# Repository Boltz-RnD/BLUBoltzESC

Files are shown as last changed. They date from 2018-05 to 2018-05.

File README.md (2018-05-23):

# DarkESC

A Remixed Board Design from The BlueESC with a large footprint and Utilizing easy to source components for a DIYer.

I've made this ESC Board Design for a College Project,but you can use it wherever however you want.

Although it may look a DIY Design but is no diffrent than a 60A version of BlueESC, It runs on a Forked Version of Simonk's TGY firmware.

Unlike other DIY ESC, This one is a lot more reliable and is much more Optimized (Thanks to the TGY Firmware). 

The Firmware for this ESC is same as that of BlueESC and can be found at https://github.com/bluerobotics/tgy

Feel Free to Contribute and develop A better smaller but still DIY-able ESC.

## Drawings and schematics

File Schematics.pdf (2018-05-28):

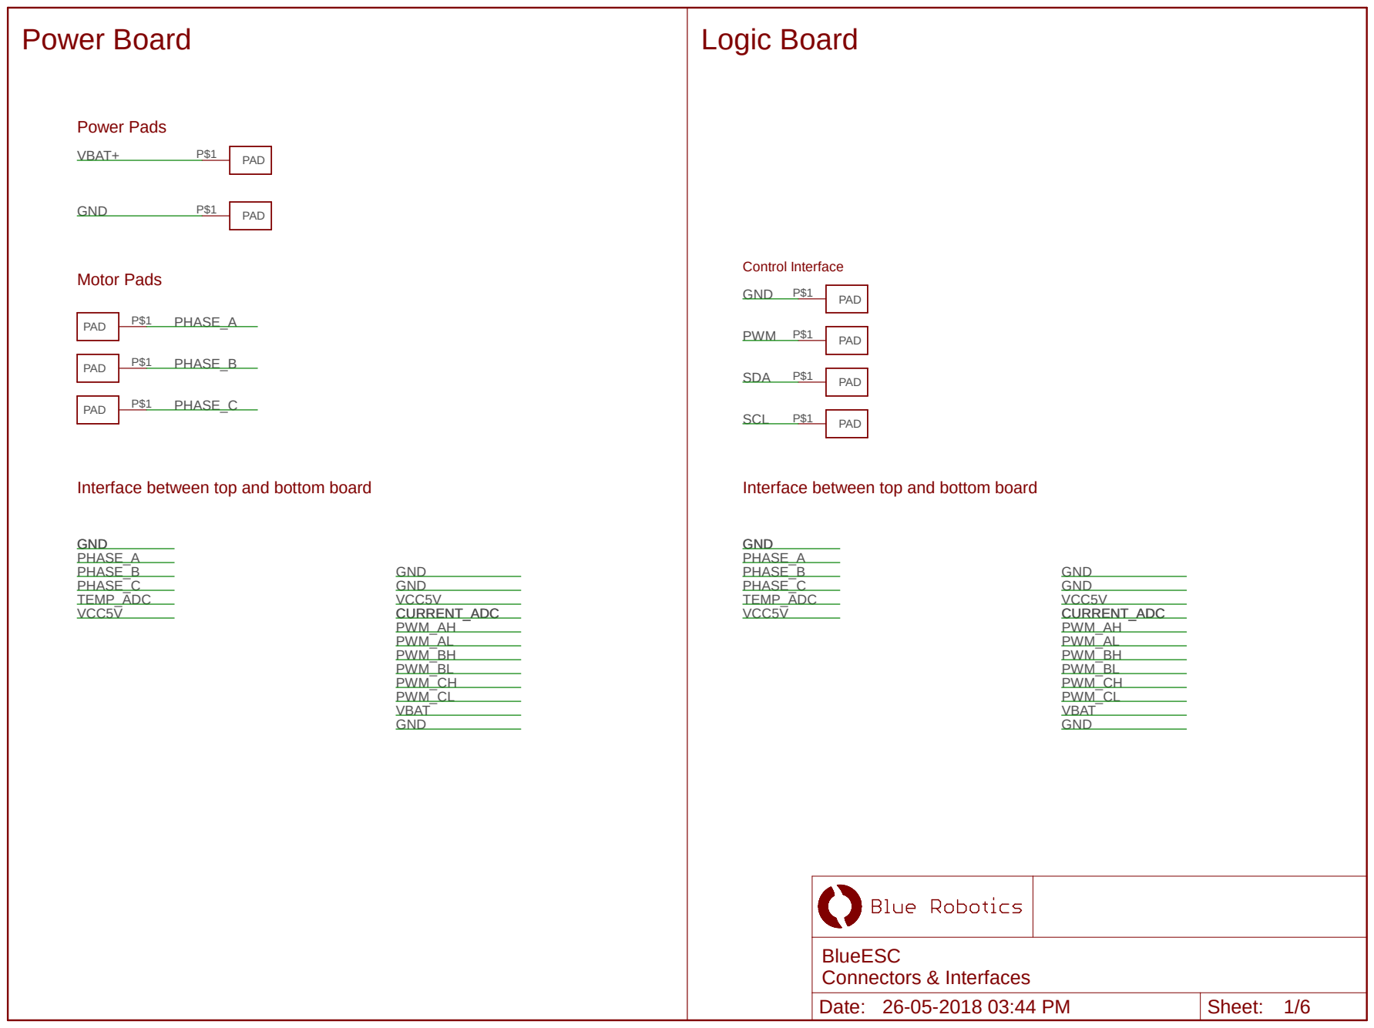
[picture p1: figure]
PAD; PAD P$1; GND; PHASE_A; PHASE_B; PHASE_C; VBAT; PWM_AL; PWM_BL; PWM_CL; TEMP_ADC; PWM_CH; PWM_BH; PWM_AH; CURRENT_ADC CURRENT_ADC; VBAT+; VCC5V; SDA; SCL; PWM; Power Pads; Motor Pads; Interface between top and bottom board; Control Interface; Power Board; Logic Board; Date: 26-05-2018 03:44 PM; Sheet: 1/6; BlueESC Connectors & Interfaces

# TP4 TP⁵ TP⁶

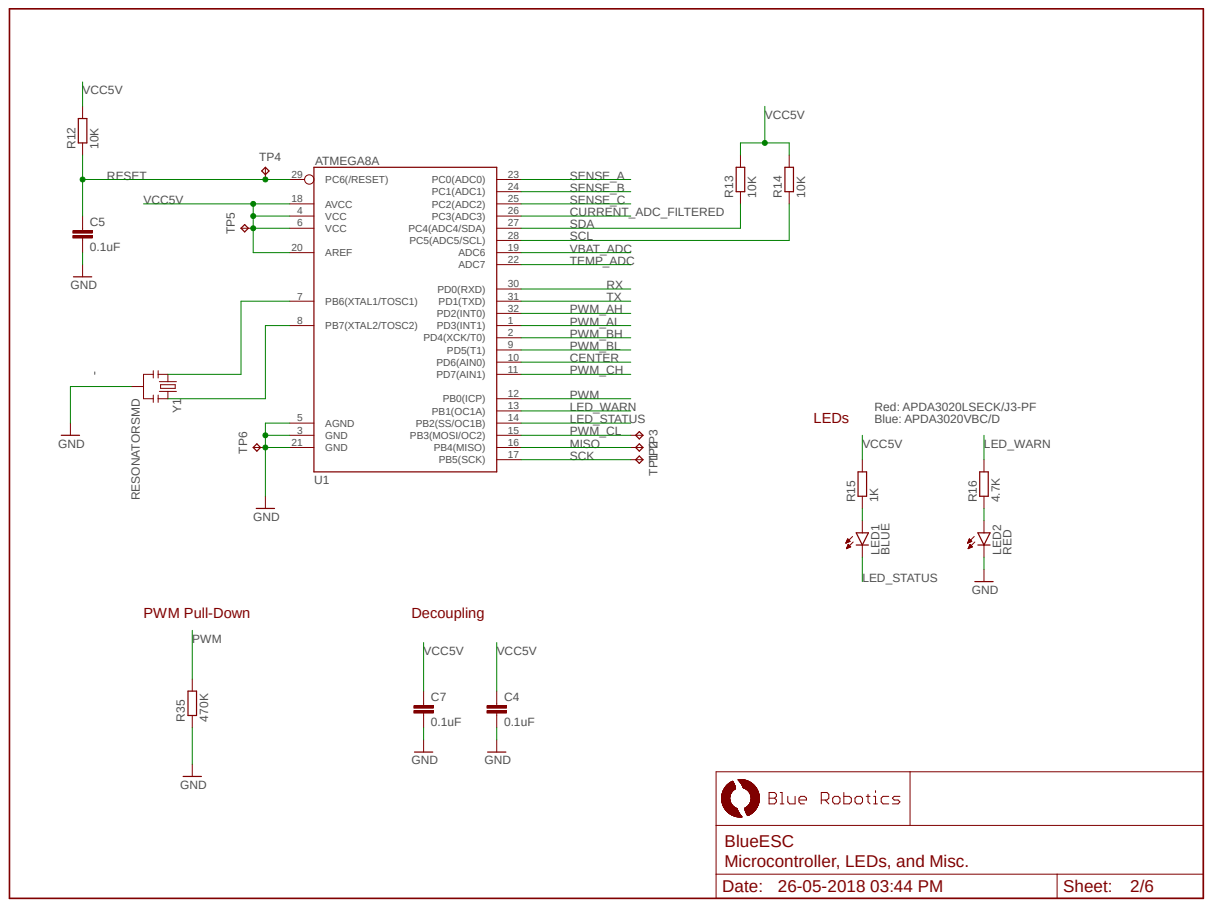
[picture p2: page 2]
ATMEGA8A; Red: APDA3020LSECK/J3-PF; Blue: APDA3020VBC/D ¹⁰K; GND; RESONATORSMD; BLUE; RED 470K; PB5(SCK); PB7(XTAL2/TOSC2) 8; PB6(XTAL1/TOSC1) 7; GND 3 GND 21; VCC 4 VCC 6; AGND 5; AREF 20; AVCC 18; PB4(MISO); 16 PB3(MOSI/OC2); 13 PB0(ICP); PD7(AIN1); 11 PD6(AIN0); PD4(XCK/T0); PD3(INT1); PD2(INT0); 32 PD1(TXD); 31 PD0(RXD); ADC7; 22 ADC6; 19 PC5(ADC5/SCL); 28 PC4(ADC4/SDA); 27 PC3(ADC3); 26 PC2(ADC2); 25 PC1(ADC1); 24 PC0(ADC0); 23 PC6(/RESET) 29; U1 R¹²; R¹³; R¹⁴ Y¹; R¹⁵; R¹⁶; LED¹; LED² R³⁵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

PWM Pull-Down

BlueESC
Microcontroller, LEDs, and Misc.

# R34R¹⁰ R¹¹

Power Board | Logic Board

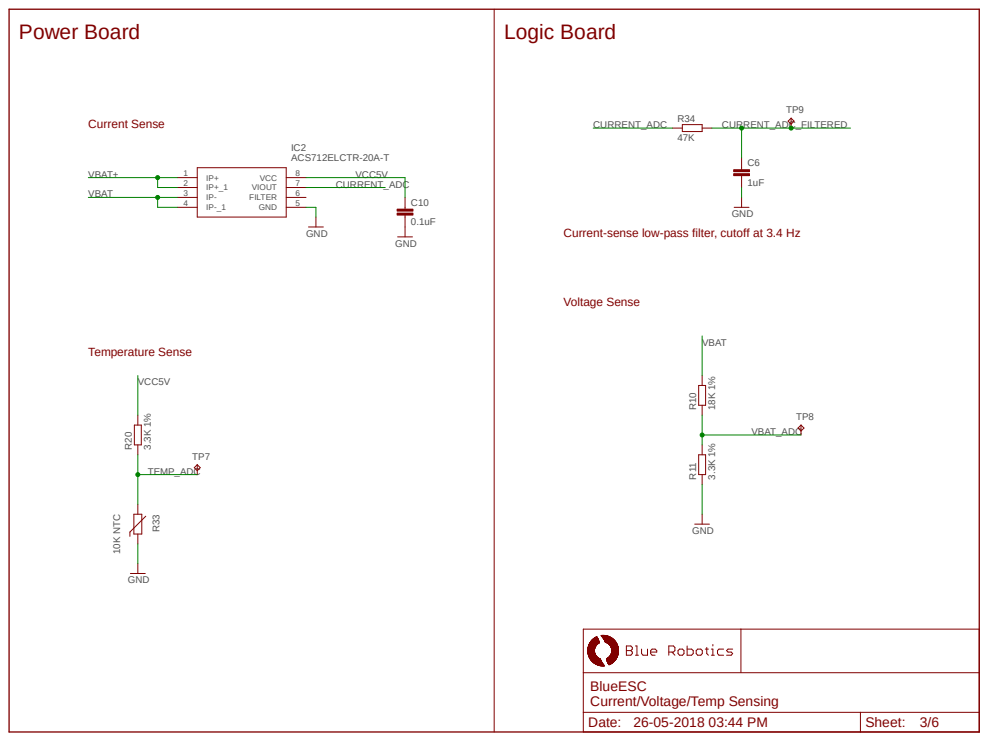
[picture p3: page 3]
GND 18K ¹% 3.3K ¹%; GND; GND 3.3K ¹% 10K NTC; ACS712ELCTR-20A-T; C10 R²⁰; R³³; VCC; VIOUT; FILTER; TP9 CURRENT_ADC_FILTERED; VBAT_ADC; VBAT; CURRENT_ADC; VBAT+; TEMP_ADC; VCC5V; Voltage Sense; Current Sense; Temperature Sense; Date: 26-05-2018 03:44 PM; Sheet: 3/6

Current-sense low-pass filter, cutoff at 3.4 Hz

BlueESC
Current/Voltage/Temp Sensing

Power Board | Logic Board

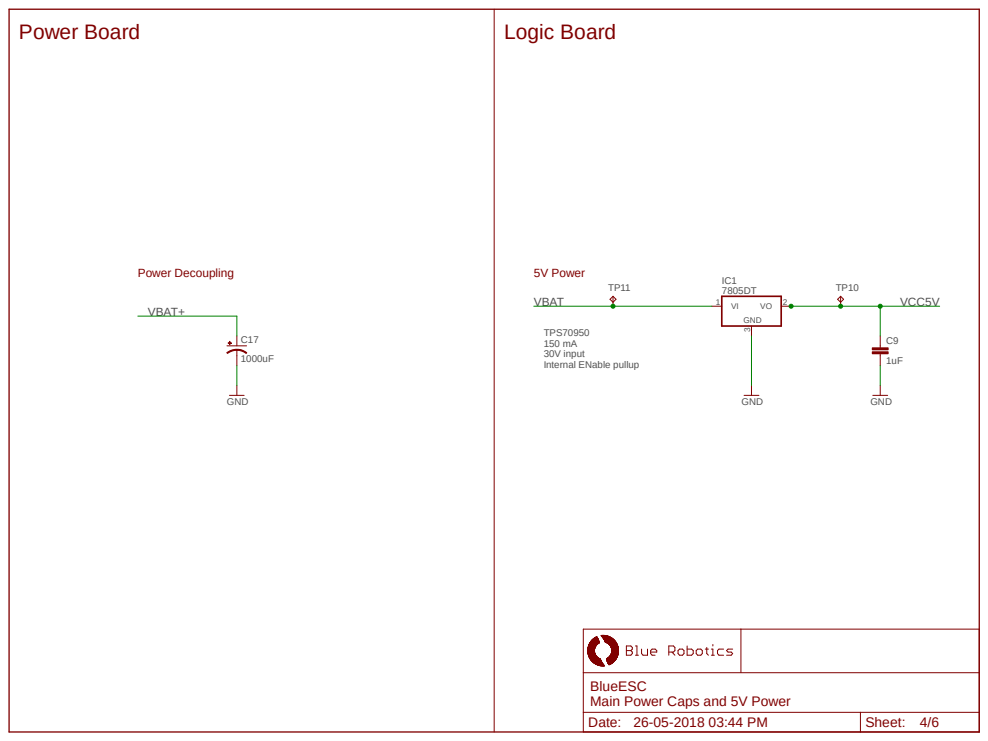
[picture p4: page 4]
TPS70950 150 mA 30V input; GND; VBAT+; VBAT; VCC5V; Power Decoupling; 5V Power; Date: 26-05-2018 03:44 PM; Sheet: 4/6

Internal ENable pullup 1000uF

BlueESC
Main Power Caps and 5V Power

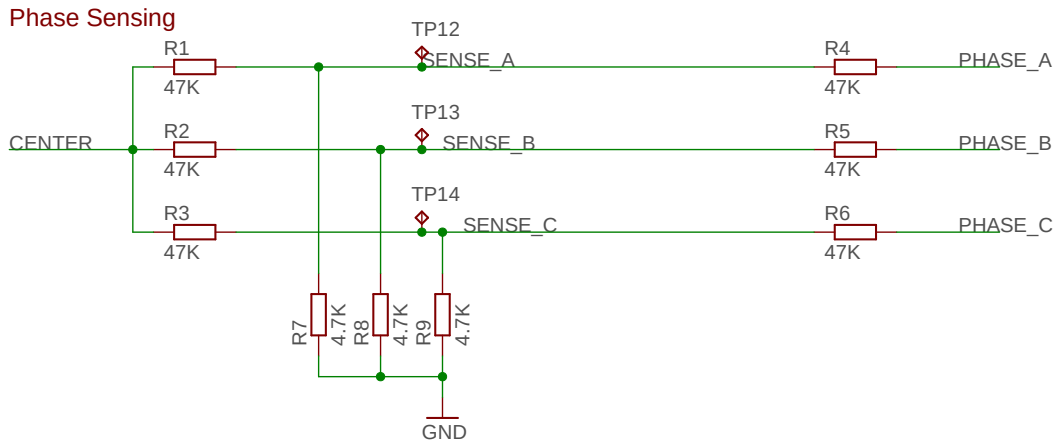
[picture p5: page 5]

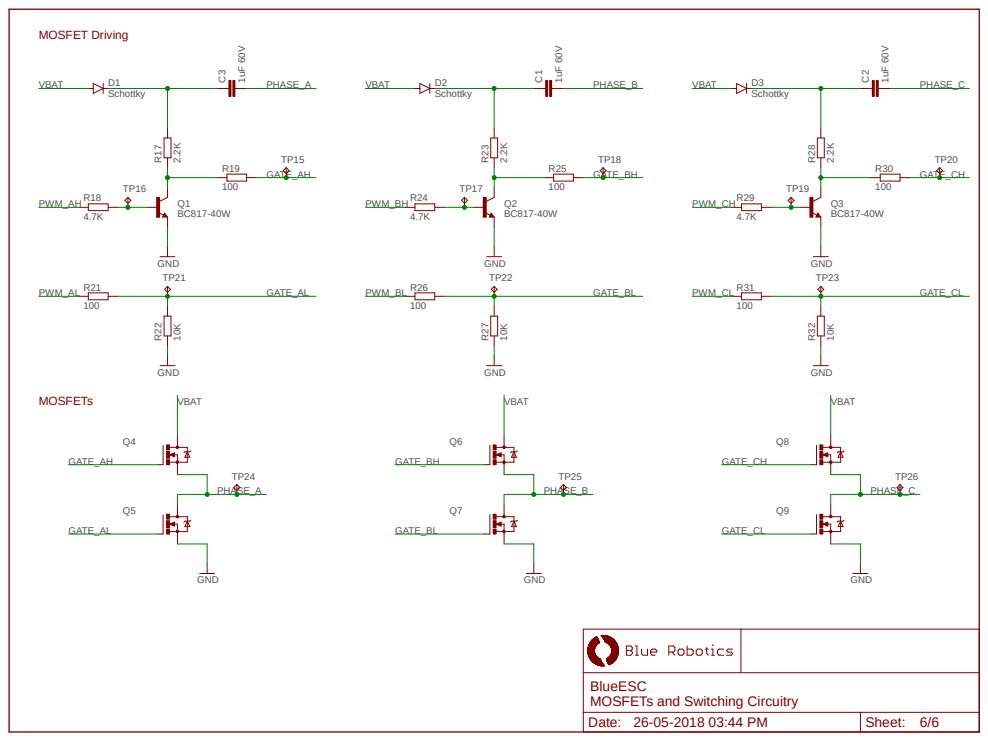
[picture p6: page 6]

BlueESC
MOSFETs and Switching Circuitry

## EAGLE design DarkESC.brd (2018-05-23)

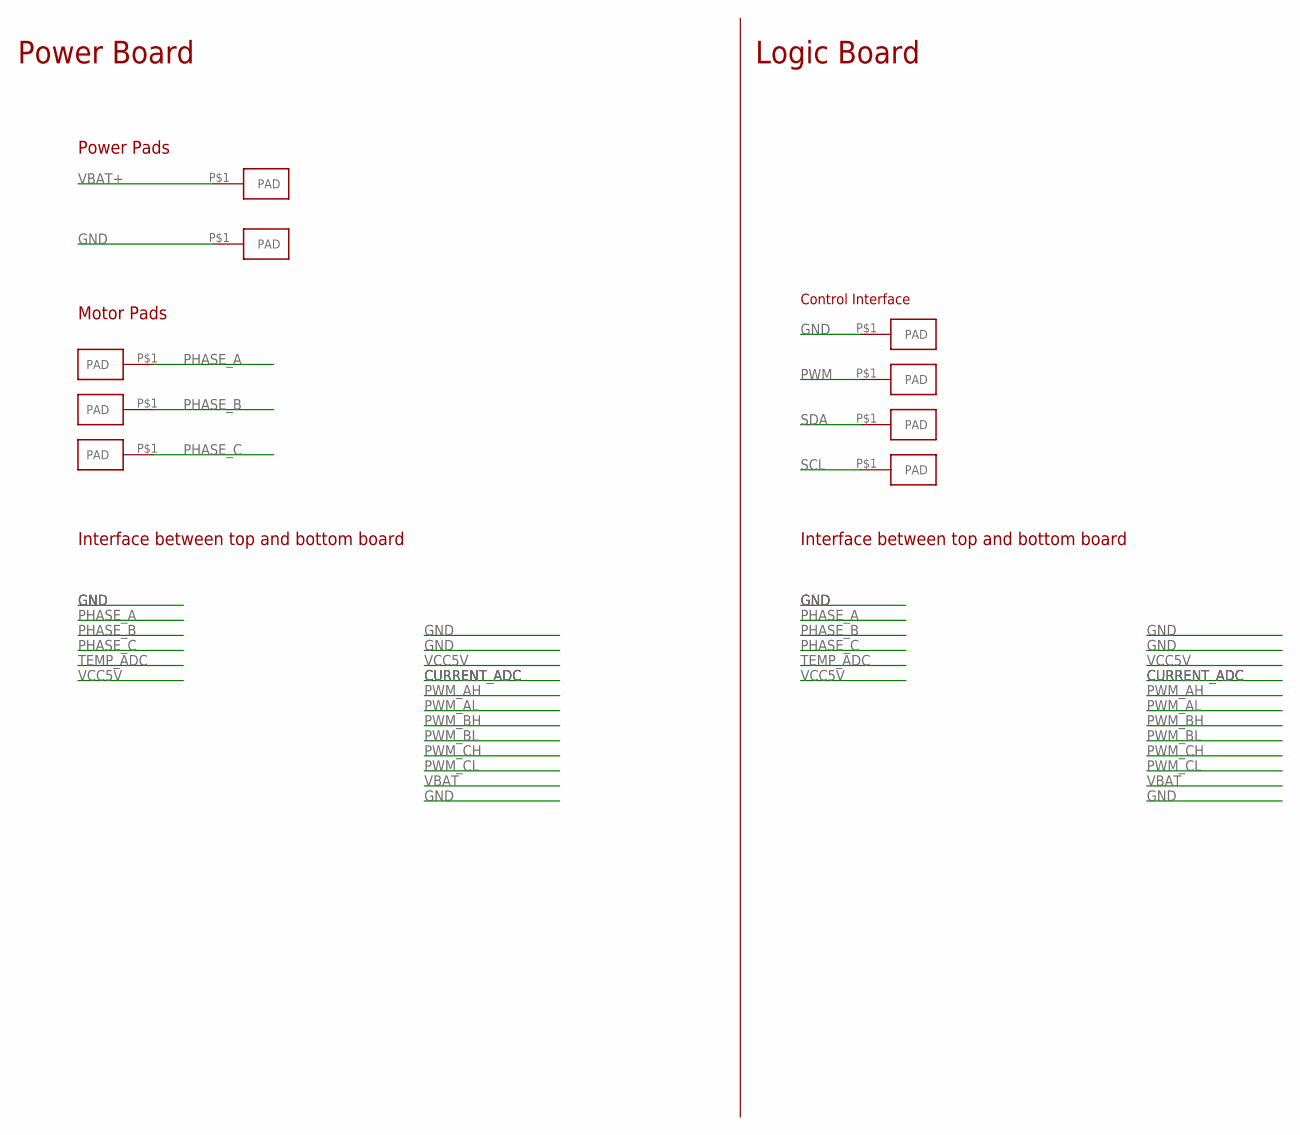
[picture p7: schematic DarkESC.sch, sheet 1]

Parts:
U$1, U$2: PADPTH-MED; PAD-PTH-MED-1
U$5, U$6, U$7: PAD18AWG; PAD-PTH-18AWG-1
U$11, U$12, U$13, U$14: PAD1.5X3MM; PAD-1.5X3MM

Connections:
GND: U$2.P$1, U$11.P$1; also elsewhere on the board
PHASE_A: U$5.P$1; also elsewhere on the board
PHASE_B: U$6.P$1; also elsewhere on the board
PHASE_C: U$7.P$1; also elsewhere on the board
PWM: U$14.P$1; also elsewhere on the board
SCL: U$13.P$1; also elsewhere on the board
SDA: U$12.P$1; also elsewhere on the board
VBAT+: U$1.P$1; also elsewhere on the board

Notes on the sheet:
Power Pads
Motor Pads
Interface between top and bottom board
Control Interface
Power Board
Logic Board

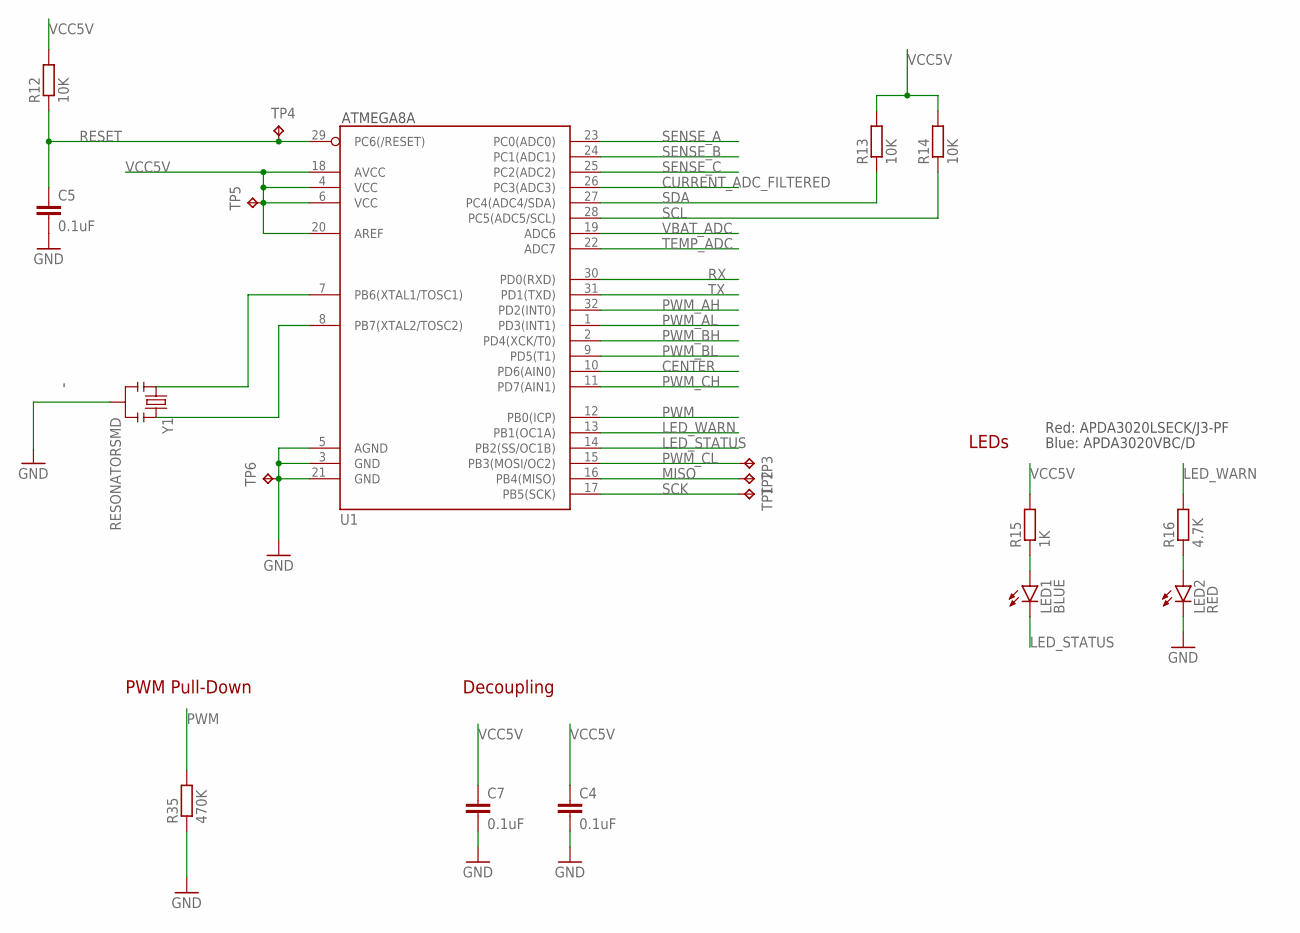
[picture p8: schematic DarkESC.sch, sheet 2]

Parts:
C4, C5, C7: 0.1uF; C3216
LED1: BLUE; SMT-LED-3X2-RA
LED2: RED; SMT-LED-3X2-RA
R12, R13, R14: 10K; R3216
R15: 1K; R3216
R16: 4.7K; R3216
R35: 470K; R3216
TP1, TP2, TP3, TP4, TP5, TP6: TPB1,27; B1,27
U1: ATMEGA168; TQFP32-08
Y1: RESONATORSMD; RESONATOR-SMD

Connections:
CENTER: U1.10 (PD6(AIN0)); also elsewhere on the board
CURRENT_ADC_FILTERED: U1.26 (PC3(ADC3)); also elsewhere on the board
GND: C4.2, C5.2, C7.2, LED2.2 (C), R35.1, TP6.TP, U1.3 (GND), U1.5 (AGND), U1.21 (GND), Y1.2; also elsewhere on the board
LED_STATUS: LED1.2 (C), U1.14 (PB2(SS/OC1B))
LED_WARN: R16.2, U1.13 (PB1(OC1A))
MISO: TP2.TP, U1.16 (PB4(MISO))
unnamed: LED2.1 (A), R16.1
unnamed: U1.7 (PB6(XTAL1/TOSC1)), Y1.1
unnamed: U1.8 (PB7(XTAL2/TOSC2)), Y1.3
unnamed: LED1.1 (A), R15.1
PWM: R35.2, U1.12 (PB0(ICP)); also elsewhere on the board
PWM_AH: U1.32 (PD2(INT0)); also elsewhere on the board
PWM_AL: U1.1 (PD3(INT1)); also elsewhere on the board
PWM_BH: U1.2 (PD4(XCK/T0)); also elsewhere on the board
PWM_BL: U1.9 (PD5(T1)); also elsewhere on the board
PWM_CH: U1.11 (PD7(AIN1)); also elsewhere on the board
PWM_CL: TP3.TP, U1.15 (PB3(MOSI/OC2)); also elsewhere on the board
RESET: C5.1, R12.1, TP4.TP, U1.29 (PC6(/RESET))
RX: U1.30 (PD0(RXD))
SCK: TP1.TP, U1.17 (PB5(SCK))
SCL: R14.1, U1.28 (PC5(ADC5/SCL)); also elsewhere on the board
SDA: R13.1, U1.27 (PC4(ADC4/SDA)); also elsewhere on the board
SENSE_A: U1.23 (PC0(ADC0)); also elsewhere on the board
SENSE_B: U1.24 (PC1(ADC1)); also elsewhere on the board
SENSE_C: U1.25 (PC2(ADC2)); also elsewhere on the board
TEMP_ADC: U1.22 (ADC7); also elsewhere on the board
TX: U1.31 (PD1(TXD))
VBAT_ADC: U1.19 (ADC6); also elsewhere on the board
VCC5V: C4.1, C7.1, R12.2, R13.2, R14.2, R15.2, TP5.TP, U1.4 (VCC), U1.6 (VCC), U1.18 (AVCC), U1.20 (AREF); also elsewhere on the board

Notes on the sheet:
ATMEGA8A
Decoupling
LEDs
Red: APDA3020LSECK/J3-PF
Blue: APDA3020VBC/D
PWM Pull-Down

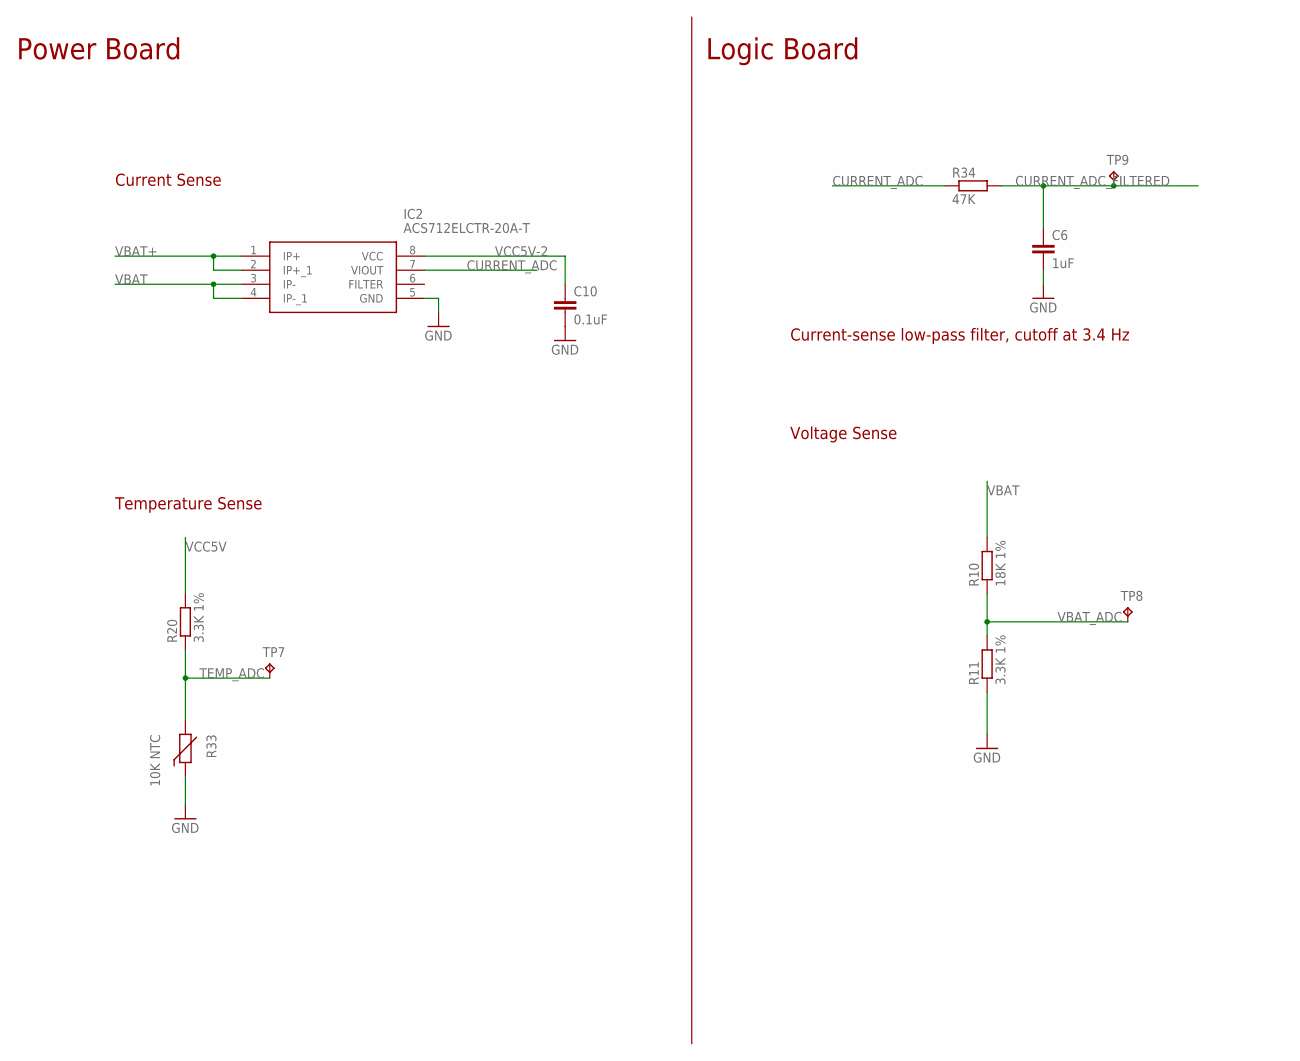
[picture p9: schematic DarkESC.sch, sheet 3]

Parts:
C6: 1uF; C3216
C10: 0.1uF; C3216
IC2: ACS712ELCTR-20A-T; SOIC127P600X175-8N
R10: 18K 1%; 0204/7
R11, R20: 3.3K 1%; 0204/7
R33: 10K NTC; RS-2,5
R34: 47K; R3216
TP7, TP8, TP9: TPB1,27; B1,27

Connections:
CURRENT_ADC: IC2.7 (VIOUT), R34.1
CURRENT_ADC_FILTERED: C6.1, R34.2, TP9.TP; also elsewhere on the board
GND: C6.2, C10.2, IC2.5 (GND), R11.1, R33.1; also elsewhere on the board
TEMP_ADC: R20.1, R33.2, TP7.TP; also elsewhere on the board
VBAT: IC2.3 (IP-), IC2.4 (IP-_1), R10.2; also elsewhere on the board
VBAT+: IC2.1 (IP+), IC2.2 (IP+_1); also elsewhere on the board
VBAT_ADC: R10.1, R11.2, TP8.TP; also elsewhere on the board
VCC5V: R20.2; also elsewhere on the board
VCC5V-2: C10.1, IC2.8 (VCC)

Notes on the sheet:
Power Board
Logic Board
Current-sense low-pass filter, cutoff at 3.4 Hz
Voltage Sense
Current Sense
Temperature Sense

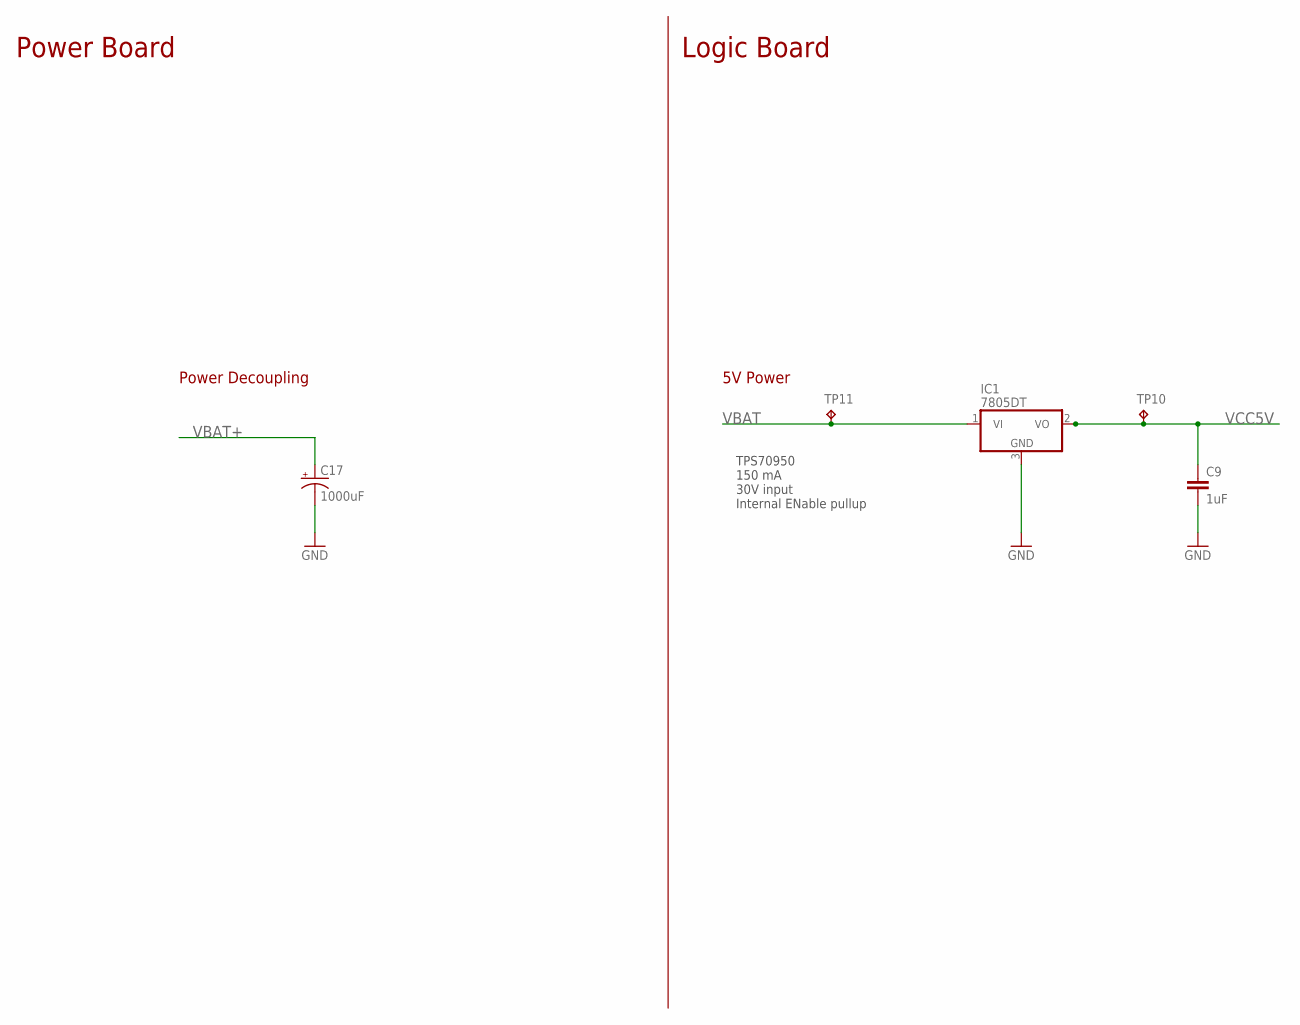
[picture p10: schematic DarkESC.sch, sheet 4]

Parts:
C9: 1uF; C3216
C17: 1000uF; CPOL-RADIAL-100UF-25V
IC1: 7805DT; TO252
TP10, TP11: TPB1,27; B1,27

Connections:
GND: C9.2, C17.2 (-), IC1.3 (GND); also elsewhere on the board
VBAT: IC1.1 (VI), TP11.TP; also elsewhere on the board
VBAT+: C17.1 (+); also elsewhere on the board
VCC5V: C9.1, IC1.2 (VO), TP10.TP; also elsewhere on the board

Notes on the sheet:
Power Board
Logic Board
Power Decoupling
5V Power
TPS70950 150 mA 30V input Internal ENable pullup

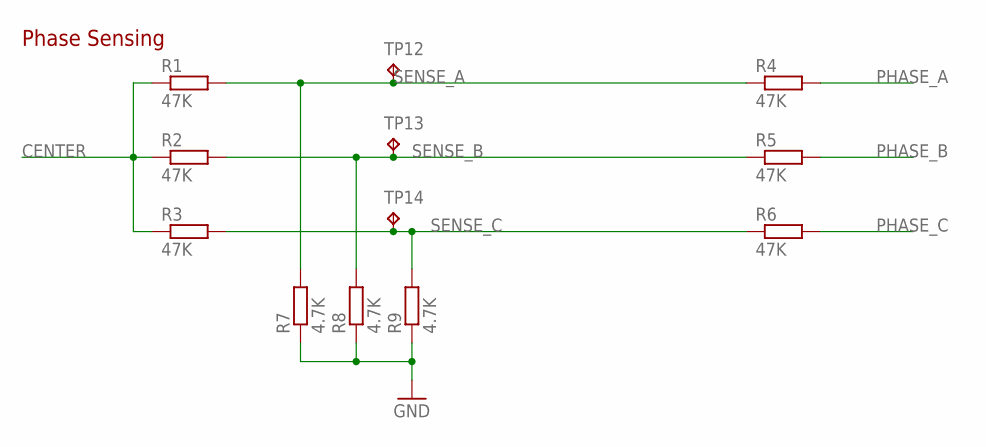
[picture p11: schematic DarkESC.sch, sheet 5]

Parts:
R1, R2, R3, R4, R5, R6: 47K; R3216
R7, R8, R9: 4.7K; R3216
TP12, TP13, TP14: TPB1,27; B1,27

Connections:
CENTER: R1.1, R2.1, R3.1; also elsewhere on the board
GND: R7.1, R8.1, R9.1; also elsewhere on the board
PHASE_A: R4.2; also elsewhere on the board
PHASE_B: R5.2; also elsewhere on the board
PHASE_C: R6.2; also elsewhere on the board
SENSE_A: R1.2, R4.1, R7.2, TP12.TP; also elsewhere on the board
SENSE_B: R2.2, R5.1, R8.2, TP13.TP; also elsewhere on the board
SENSE_C: R3.2, R6.1, R9.2, TP14.TP; also elsewhere on the board

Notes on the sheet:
Phase Sensing

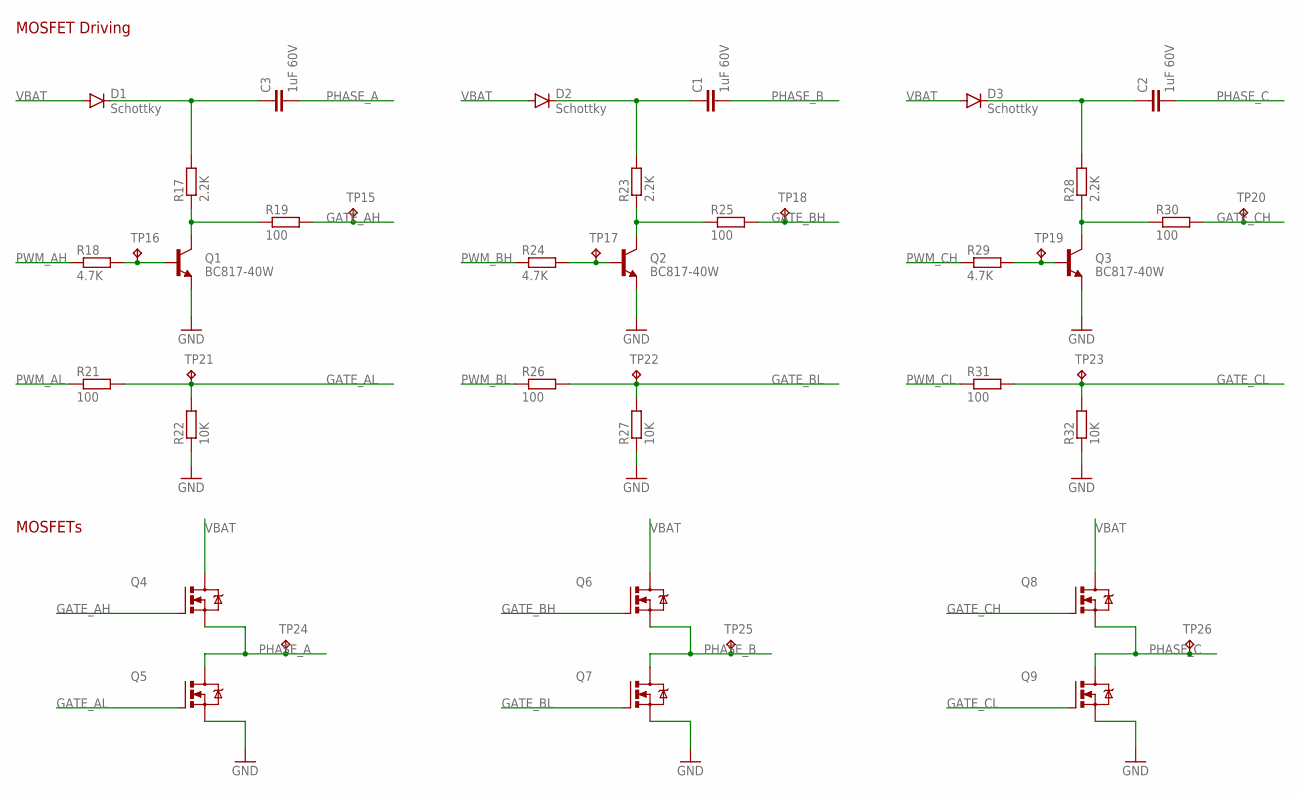
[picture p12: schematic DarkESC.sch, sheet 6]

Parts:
C1, C2, C3: 1uF 60V; C3216
D1, D2, D3: Schottky; SMB-DIODE
Q1, Q2, Q3: BC817-40W; SOT23
Q4, Q5, Q6, Q7, Q8, Q9: IRF520; TO220BV
R17, R23, R28: 2.2K; R3216
R18, R24, R29: 4.7K; R3216
R19, R21, R25, R26, R30, R31: 100; R3216
R22, R27, R32: 10K; R3216
TP15, TP16, TP17, TP18, TP19, TP20, TP21, TP22, TP23, TP24, TP25, TP26: TPB1,27; B1,27

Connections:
GATE_AH: Q4.G, R19.2, TP15.TP
GATE_AL: Q5.G, R21.2, R22.2, TP21.TP
GATE_BH: Q6.G, R25.2, TP18.TP
GATE_BL: Q7.G, R26.2, R27.2, TP22.TP
GATE_CH: Q8.G, R30.2, TP20.TP
GATE_CL: Q9.G, R31.2, R32.2, TP23.TP
GND: Q1.2 (E), Q2.2 (E), Q3.2 (E), Q5.S, Q7.S, Q9.S, R22.1, R27.1, R32.1; also elsewhere on the board
unnamed: Q1.1 (B), R18.2, TP16.TP
unnamed: Q1.3 (C), R17.1, R19.1
unnamed: Q2.1 (B), R24.2, TP17.TP
unnamed: Q2.3 (C), R23.1, R25.1
unnamed: Q3.1 (B), R29.2, TP19.TP
unnamed: Q3.3 (C), R28.1, R30.1
unnamed: C3.1, D1.C, R17.2
unnamed: C1.1, D2.C, R23.2
unnamed: C2.1, D3.C, R28.2
PHASE_A: C3.2, Q4.S, Q5.D, TP24.TP; also elsewhere on the board
PHASE_B: C1.2, Q6.S, Q7.D, TP25.TP; also elsewhere on the board
PHASE_C: C2.2, Q8.S, Q9.D, TP26.TP; also elsewhere on the board
PWM_AH: R18.1; also elsewhere on the board
PWM_AL: R21.1; also elsewhere on the board
PWM_BH: R24.1; also elsewhere on the board
PWM_BL: R26.1; also elsewhere on the board
PWM_CH: R29.1; also elsewhere on the board
PWM_CL: R31.1; also elsewhere on the board
VBAT: D1.A, D2.A, D3.A, Q4.D, Q6.D, Q8.D; also elsewhere on the board

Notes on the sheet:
MOSFETs
MOSFET Driving

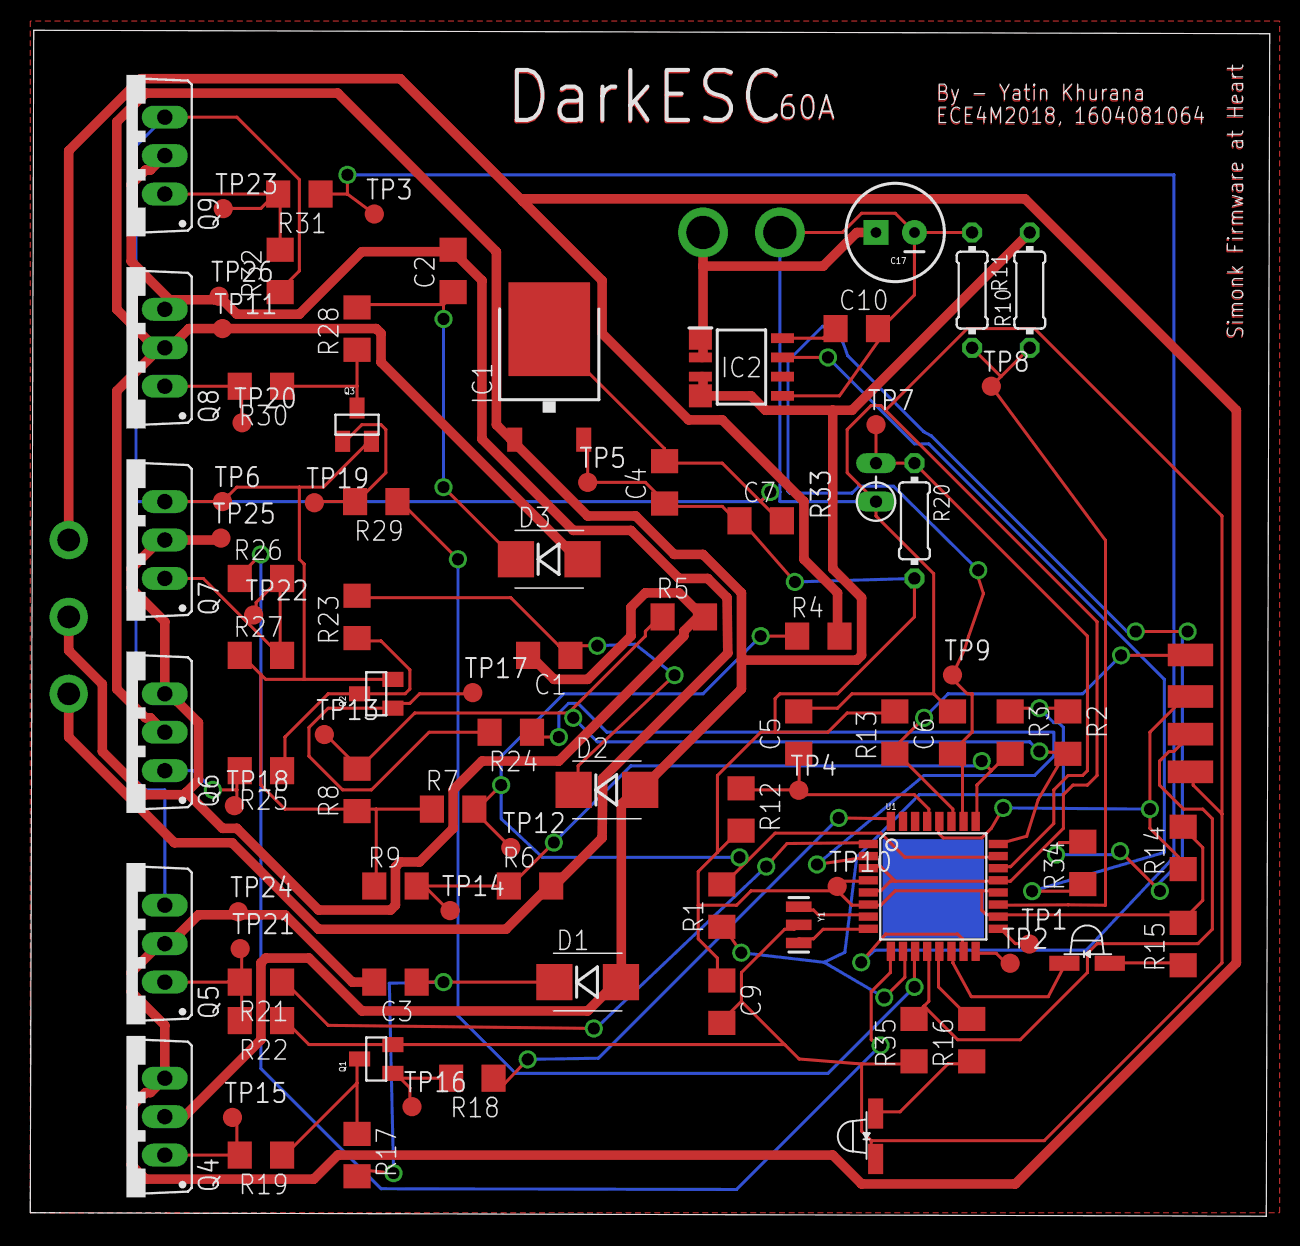
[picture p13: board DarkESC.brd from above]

Board: 2 copper layers, 81.9 x 78.4 mm, 98 parts (0 on the bottom side), 49 nets.

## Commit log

2018-03-31 Version 1.1 For BlueBoltzESC Board
    In this Version, The board is updated with a single board footprint, which minimizes hassles...
    [BlueBoltzESC.brd, BlueBoltzESC.sch]
2018-05-23 Improved the board
    Replaced IRFZ44n with IRLB4132
    Used more Easily Source-able SMD Components
    [DarkESC.brd, DarkESC.sch]
2018-05-23 Update ReadME
    Updated new name for the board
2018-05-28 added schematics pdf

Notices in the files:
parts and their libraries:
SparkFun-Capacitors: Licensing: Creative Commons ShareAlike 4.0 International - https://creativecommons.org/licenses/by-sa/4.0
